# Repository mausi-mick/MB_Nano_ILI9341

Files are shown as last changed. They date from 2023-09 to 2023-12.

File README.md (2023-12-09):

.
    Test Board für Arduino „NANOs“ mit ILI9341, ILI9488-bzw. ST7735 SPI-Display

Bei vielen meiner Projekte  verwende ich den Arduino NANO oder Pin-kompatible Prozessoren mit dem TFT-Farb-Display ILI9341 bzw. ILI9488 bzw. ST7735 aus folgenden Gründen:
  
    • Existenz vieler Bibliotheken (libs) mit zahlreichen Beispielen für Prozessor und Display
    • kompaktes Board mit relativ grosser Anzahl herausgeführter Pins für andere Funktionen,
    • leicht beschaffbar / preisgünstig
    • Existenz von „NANO“  Boards mit anderem Processor mit NANO-“Pin-mapping“
    • mit HW-SPI ist das Display -auch am NANO – relativ schnell
    • die SPI-Displays ILI9341, ILI9488 und ST7735 haben gleiche/ähnliche Pinbelegung 
    • unterschiedliche Displaygrössen (1.8“,2,4“,2.8“,3.2“.3.5“,4“) (mit/ohne Touch) erhältlich
    • unterschiedliche Auflösungen (128x160), (240x320), (320x 400)

mittlerweile sind zum Arduino-NANO pinkompatible Boards erhältlich, z.B. :
  
    • LGT8F328P----»Mini EVB Nano style“, Prozessor: modifzierter ATMega328
    • Arduino EVERY:                                     Prozessor: ATMega4809
    • Arduino NANO ESP32                           ,Prozessor: ESP32
    • Arduino NANO 33 BLE                         ,Prozessor: nRF52840
    • Arduino NANO 33 IOT                         , Prozessor: M0+SAMD21
    • Arduino NANO RP2040 Connect          ,Prozessor: RP2040

Die neueren Boards sind dann eher auf 3,3 V Logik ausgerichtet bzw. z.T. umlötbar.

Als Entwickler möchte ich eigentlich möglichst schnell zur Anwendung kommen und mich nicht 
mit den Logik-Leveln rumschlagen , sondern den Prozessor und das Display auf ein
Board setzen und mit der Entwicklung loslegen., möglichst ohne viele Leitugen zu verlegen. 

Daher habe ich dieses Board entwickelt, auf dem Steckfassungen für das Display und das „NANO“-Board angeordnet sind und zusätzlich noch Steck Buchsen für:
    • einen DUAL-DAC MCP48x2
    • bis zu vier Drehencoder ( bzw. Potis),
    • vier Drucktaster
    • vier LED Anzeigen
    • ein Mini-Breadboard 
    • negative Sapnnungsquelle(-5V / ca 100mA) für Oper.verstärker

Das SPI-Display ( ILI9341, ILI9488, ST7735) wird direkt auf das Board gesteckt , auf dem sich die Verdrahtung für die Spannungsversorgung und die SPI-Anschlüsse (CS (Chipselect) an D10, DC (Data/Control) an D9)  des Displays befindet. Die Touch Pins und die SD-Karten Pins des Displays sind auf Buchsenleisten herausgeführt, ebenso wie alle Prozessor-Pins.

Es sind Displays in den Grössen 1.8“(ST7735), 2.4, 2.8 , 3.2“ (ILI9341) bzw. 3.5, 4.0“ (ILI9488) verwendbar.

Alles ist auf einer einlagigen Platine im Europa-Format (160x100) untergebracht.
Die Stromversorgung des Boards und die Programmierung erfolgt vom PC / Notebook über ein USB-Kabel, der Strom ist mit  500 mA abgesichert.
Ist die Programmierung abgeschlossen, kann das Board auch über eine USB Powerbank betrieben werden.

Nur für grössere Verbraucher (Servos, Motoren, Relais,…) wird eine zusätzliche entsprechend
dimensionierte Spannungsversorgung benötigt.

Von diesem „Main“ Board sind die „NANO“ Boards zur Programmierung über kurze USB Kabel verbunden, je nach Board mit Mini-USB (NANO), Micro-USB (Arduino EVERY, LTG8F328) oder
USB-C (LGT8F328 (blaue Platine),.

Zu dem Board gibt es KiCad-files (KiCad 7.0) und ein Blockdiagramm (DrawIO), auch als pdf.

Ausserdem gibt es noch zwei Adapter-Platinen für
den  
            Adafruit-Metro Mini 328
   
und den

            Raspberry PICO RP2040 (W) 
  Ausserdem werden Testprogramme zu den einzelnen Boards und Displays beigefügt.

   Hardware-Komponenten

hier sind jetzt nur die wesentlichen Komponenten / Module aufgeführt, die Details kann man den KiCad Stücklisten entnehmen.

    • ILI9341 SPI-Display (2.4“, 2.8“ oder 3.2“) (Touch bzw ohne Touch) (240x320 Pixel)
    • bzw ILI9488 Display (3,5“ bzw. 4.0“)  (Touch bzw ohne Touch) (320x400 Pixel)
    • bzw. ST7735 Display( 1.8“)  ohne Touch (128x160 Pixel)
    • Arduino NANO  oder Varianten gleicher Pin-Belegung 
    • USB C Buchse zur Verbindung PC/Notebbok
    • USB-A-Buchsezur Verbindung zum Prozesorboard
    • je nach Prozessorboard kurzes USB-Kabel mit mini-, micro USB-Stecker / USB-C-Stecker
    • diverse Buchsenleisten Raster 2.54 mm
    • LDO variabel ( MC33269) für 3.7V aus 5V
    • Schiebeschalter/Kippscahlter 1x UM)
    • diverse Widerstände, Kondenatoren ,  Dioden und Sicherungen
    • optional:
    •    DualDAC MCPM4802, MCP4812, MCP4822 ( 8, 10,12 bit SPI 
    •    1x DIL8-Fassung
    •    4xButtonSwitch
    •    4xLeds
    •    Dreh-Encoder (0-4 Stück)  ??
    •    Mini-Bread-Board
    •    -negatve Spannungsverorgung mit ICL7662 Modul
    •   Adapterboards für Adafruit Metro-Mini 328 / Raspberry PI RP2040

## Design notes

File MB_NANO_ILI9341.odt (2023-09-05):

MB_NANO_ILI9341

The MB_NANO_ILI9341 is a small „Motherboard“ (160mmx100mm) for developing projects with microprocessor boards with formfactor Arduino NANO (boards: NANO, EVERY, NANO ESP32 , LGT8F328…) and then TFT-Display ILI9341 (3,2“,2,8“, 2.4“).

There are sockets for them and also for other often used devices like rotary encoders / potentiometers , button-switches, LEDs

Powerd via USB connection From PC or Notebook.

You can use it with 5V or 3,3V logic level.

At this time testedt with NANO, NANO EVERY, LGT8f328P and Adafruit METRO Mini 328 (with other PinOut/Pinmapping).

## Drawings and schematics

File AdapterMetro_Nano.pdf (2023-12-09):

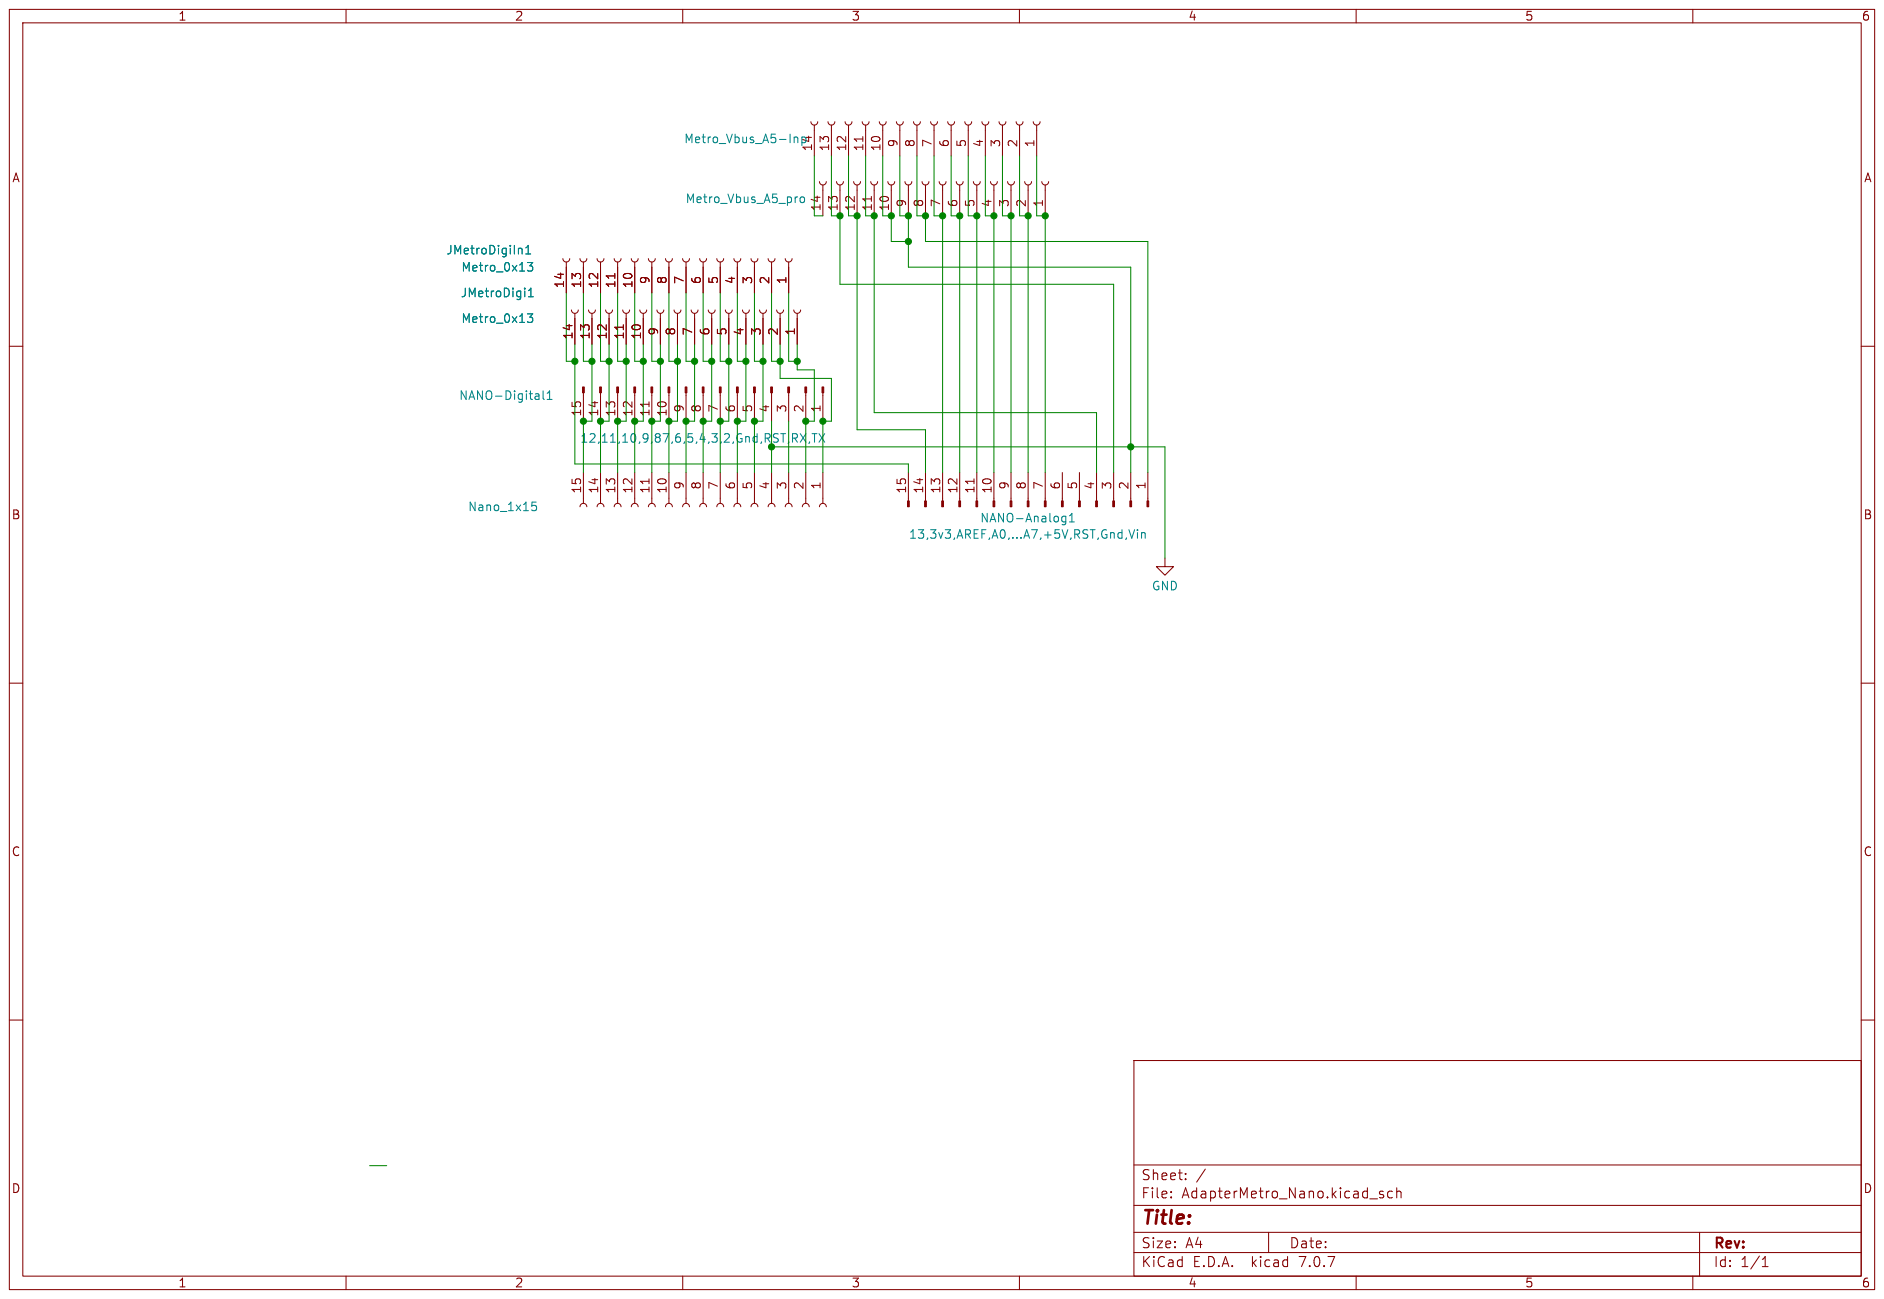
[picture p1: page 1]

12,11,10,9,87,6,5,4,3,2,Gnd,RST,RX,TX

Id: 1/1 Title: File: AdapterMetro_Nano.kicad_sch Sheet: /

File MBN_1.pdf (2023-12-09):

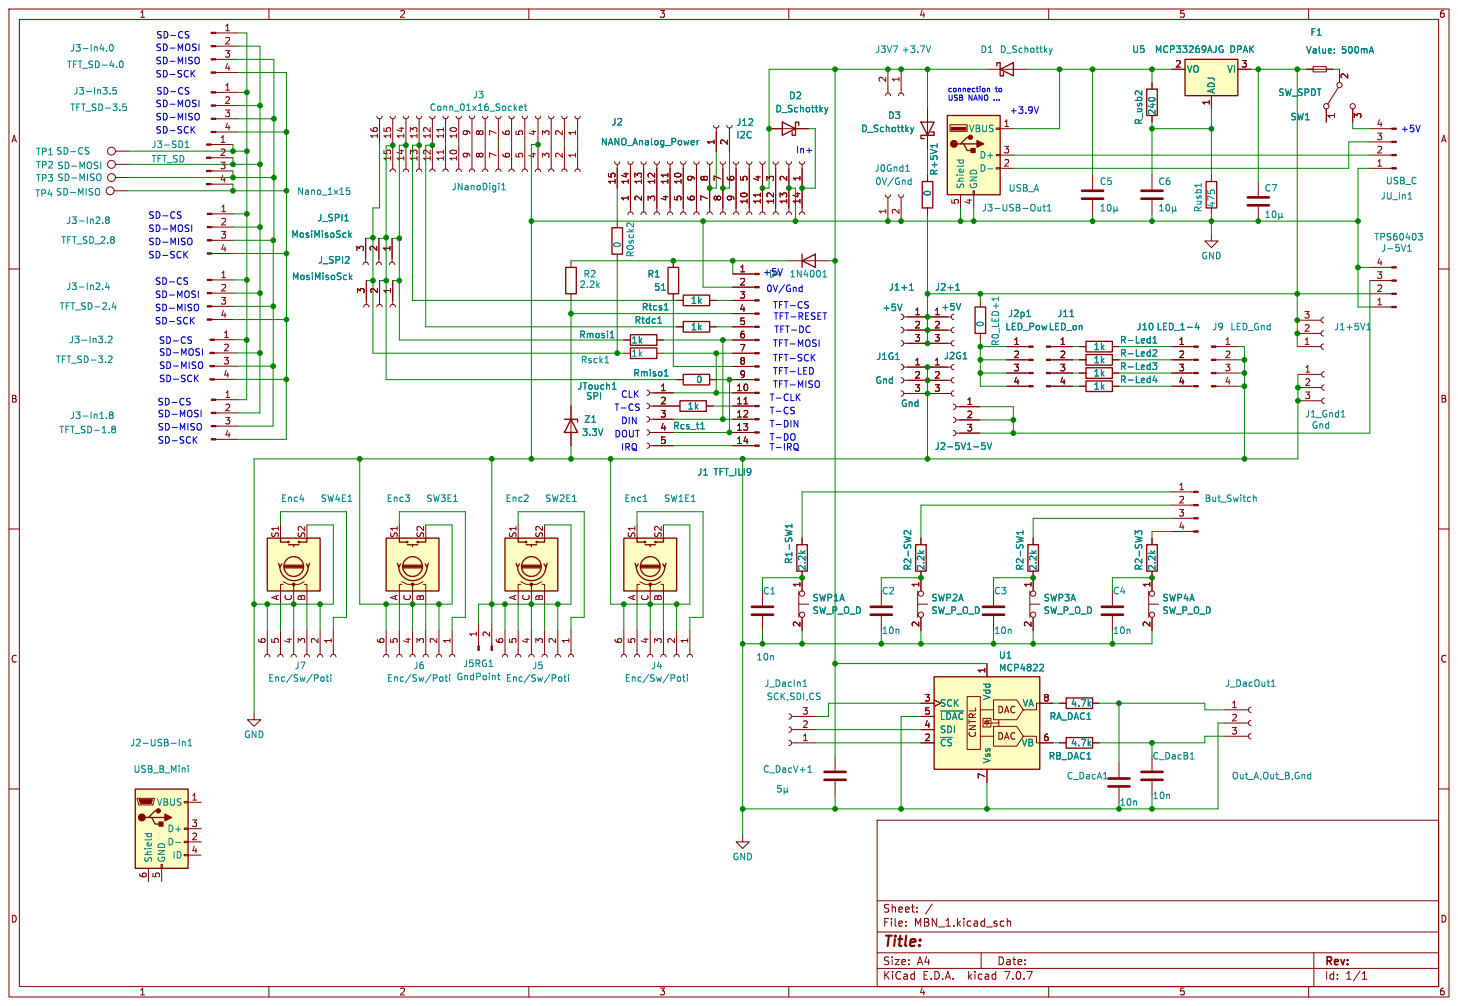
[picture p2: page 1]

SD-MOSI SD-CS
J3-USB-Out1 USB_A D1 D_Schottky SD-SCK

SD-MOSI SD-SCK
SD-MISO

J3-SD1 TFT_SD TP2 SD-MOSI TP3 SD-MISO

1 ~{CS} 2 SCK 3 SDI 4 ~{LDAC} 5 VB 6 Vss 7 VA 8 U1 MCP4822

1 ~{CS} 2 SCK 3 SDI 4 ~{LDAC} 5 VB 6 Vss 7 VA 8RB_DAC1

Id: 1/1 Title: File: MBN_1.kicad_sch Sheet: /

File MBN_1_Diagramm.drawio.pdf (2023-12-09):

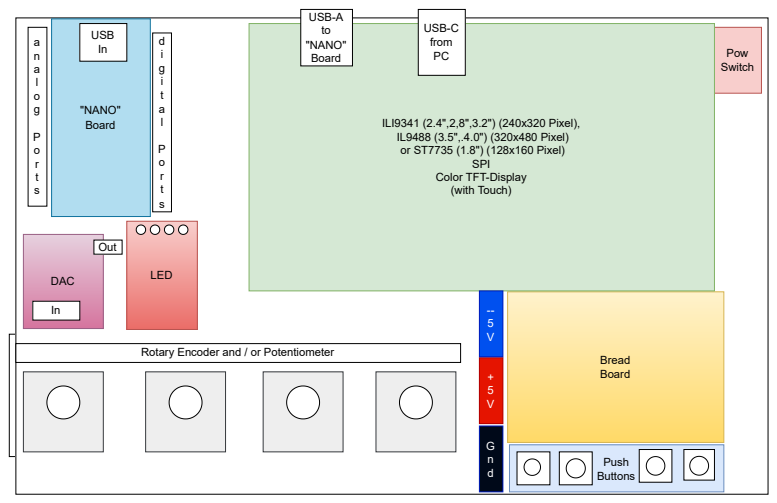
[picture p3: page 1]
"NANO" Board; DAC; Bread Board; Push Buttons; Pow Switch; LED; USB In; Out; ILI9341 (2.4",2,8",3.2") (240x320 Pixel), IL9488 (3.5",.4.0") (320x480 Pixel) or ST7735 (1.8") (128x160 Pixel); USB-A to "NANO" Board; USB-C from PC

SPI
Color TFT-Display
(with Touch)

Rotary Encoder and / or Potentiometer

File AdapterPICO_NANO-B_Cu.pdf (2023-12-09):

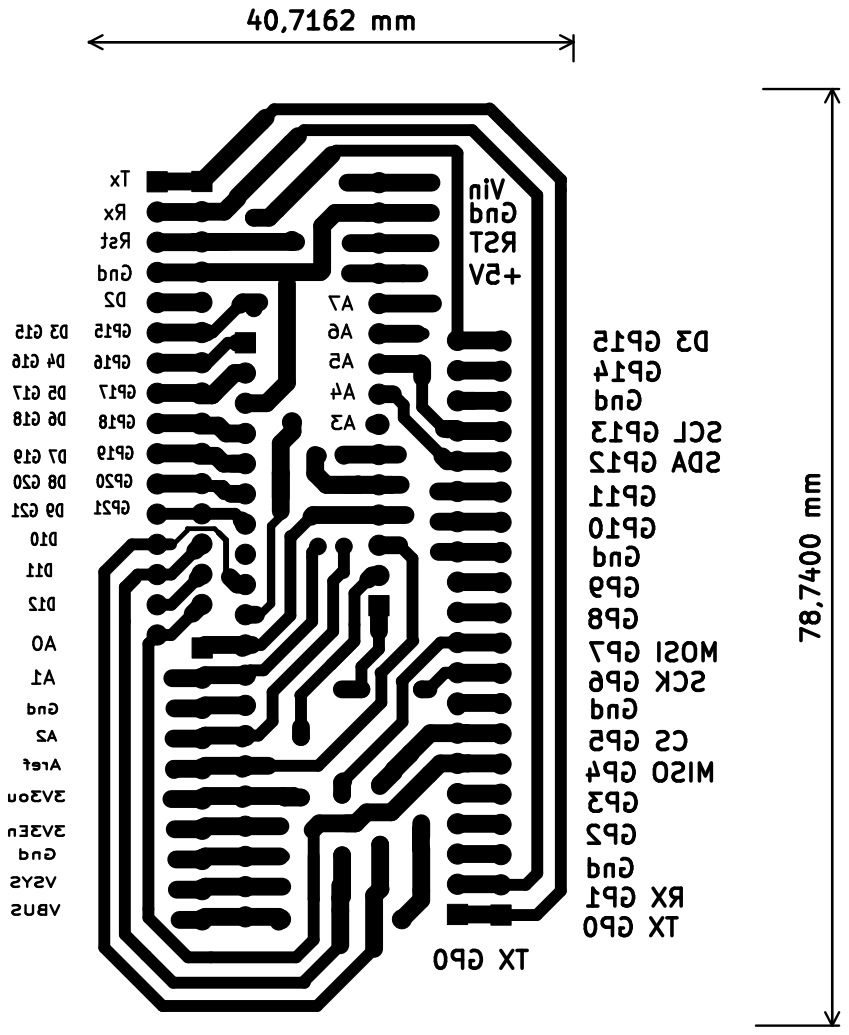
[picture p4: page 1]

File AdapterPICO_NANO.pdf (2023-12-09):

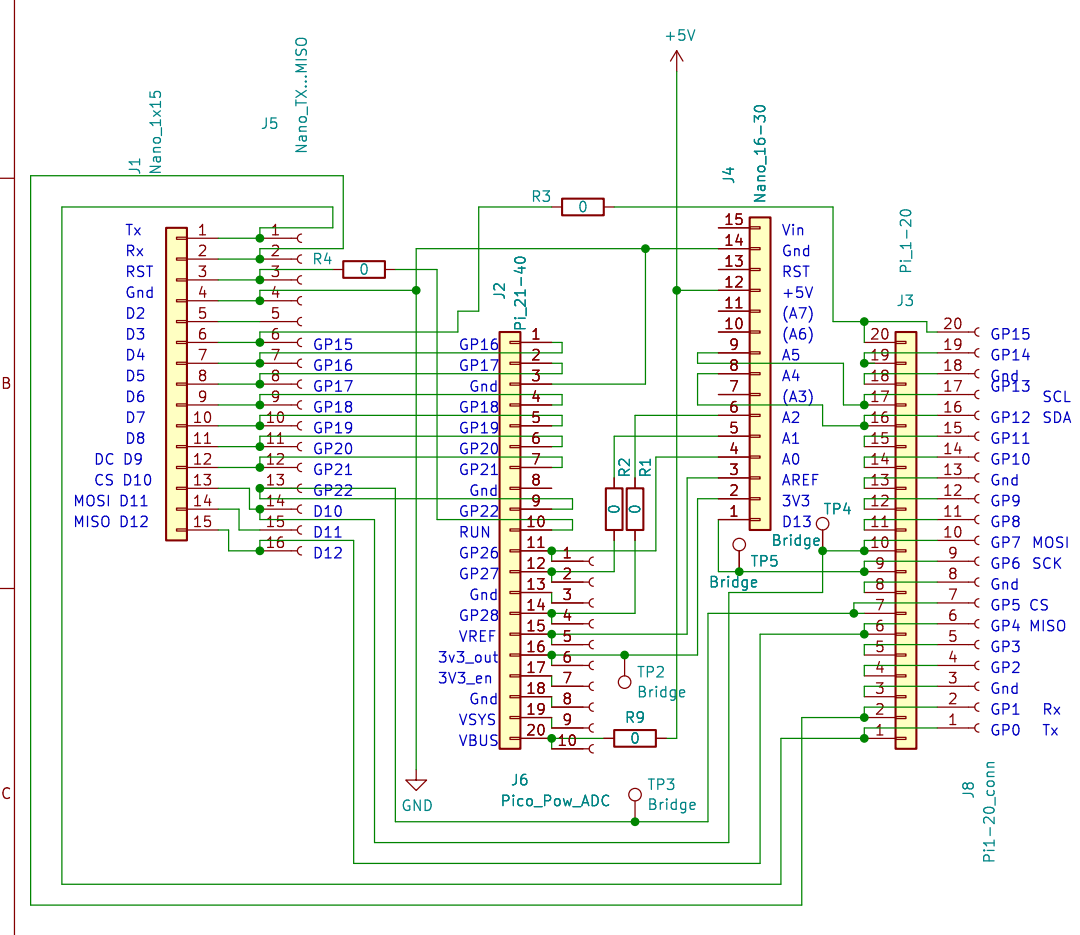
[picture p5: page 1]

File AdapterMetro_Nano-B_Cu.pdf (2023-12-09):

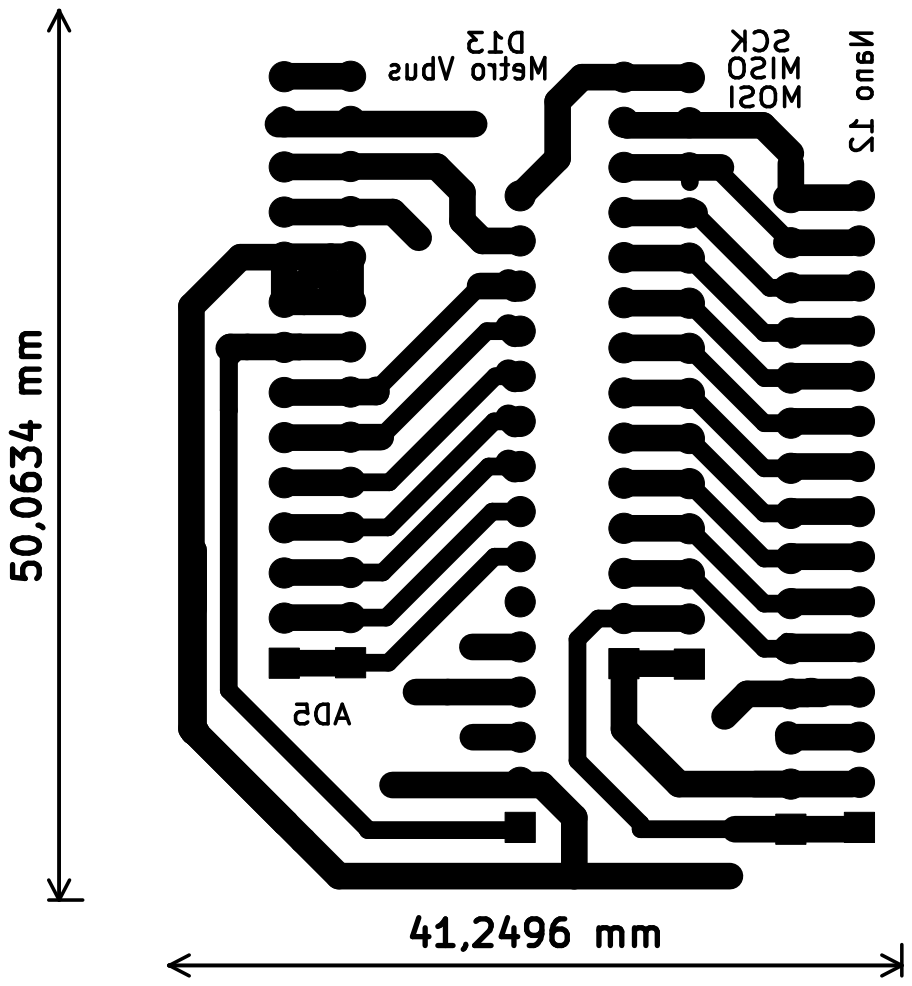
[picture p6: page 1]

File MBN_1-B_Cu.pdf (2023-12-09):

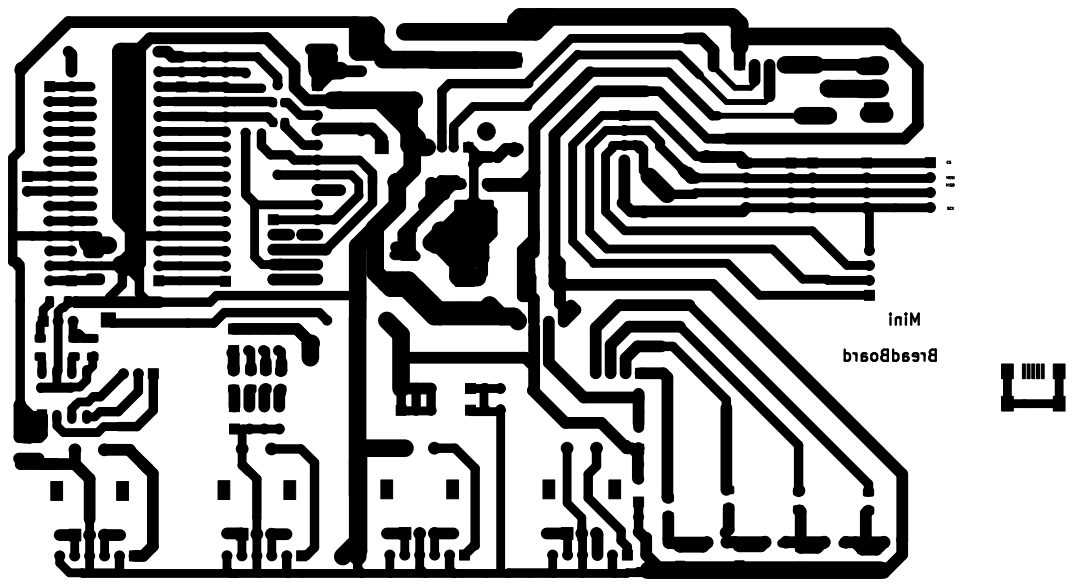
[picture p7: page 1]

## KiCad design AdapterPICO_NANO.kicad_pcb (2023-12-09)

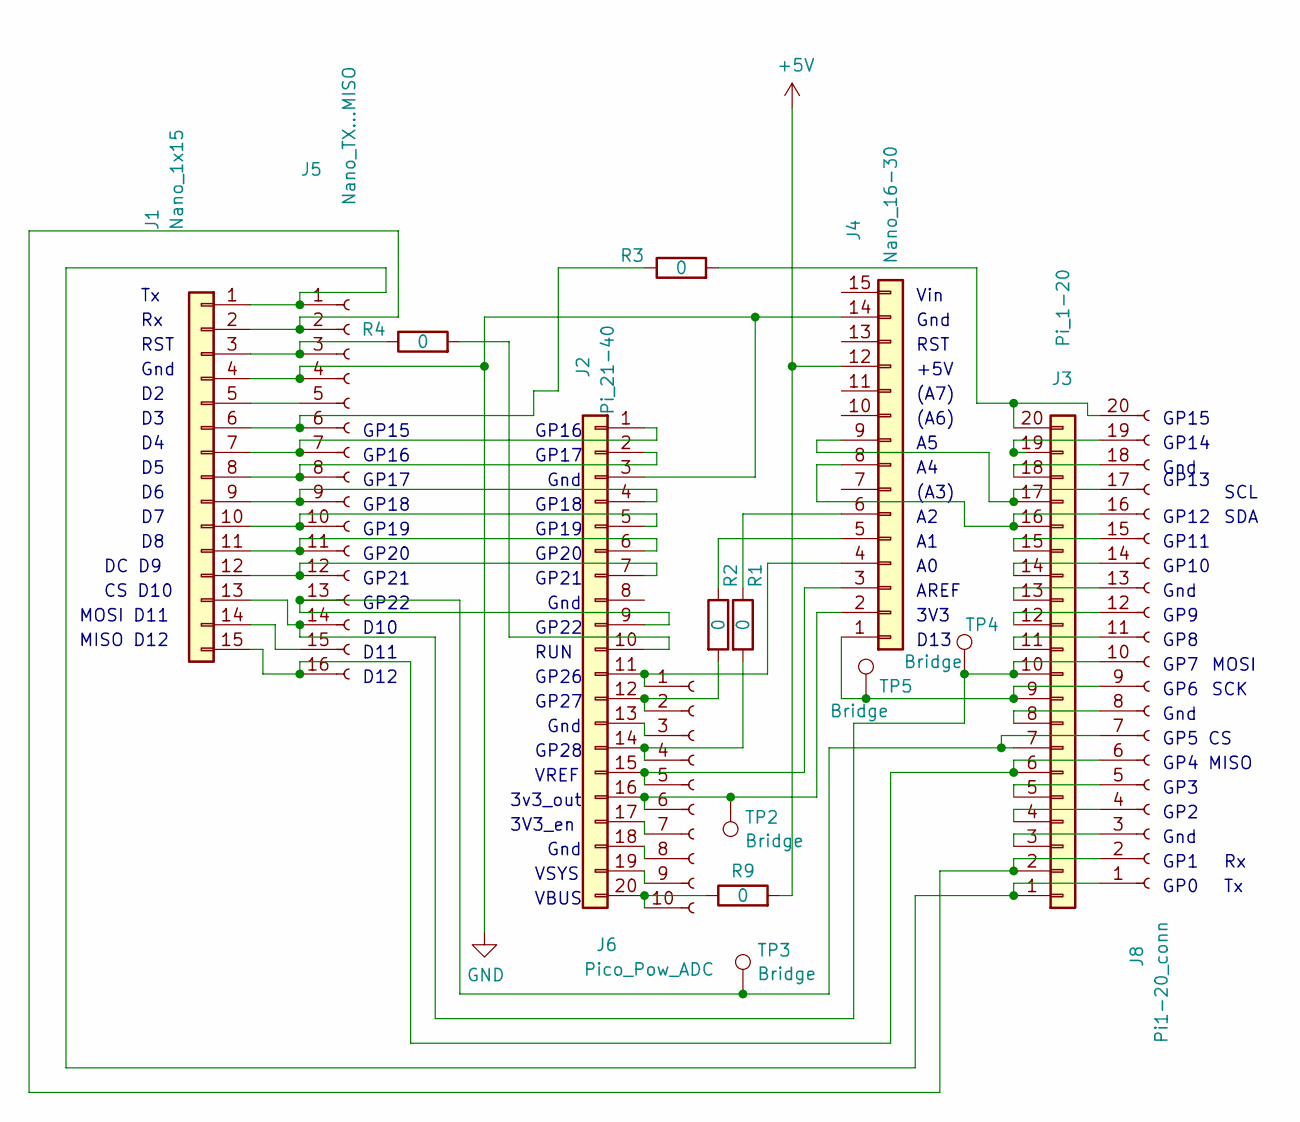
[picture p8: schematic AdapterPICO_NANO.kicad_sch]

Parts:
J1: Nano_1x15; PinHeader_1x15_P2.54mm_Vertical
J2: Pi_21-40; PinSocket_1x20_P2.54mm_Vertical
J3: Pi_1-20; PinSocket_1x20_P2.54mm_Vertical
J4: Nano_16-30; PinHeader_1x15_P2.54mm_Vertical
J5: Nano_TX...MISO; PinSocket_1x16_P2.54mm_Vertical
J6: Pico_Pow_ADC; PinSocket_1x10_P2.54mm_Vertical
J8: Pi1-20_conn; PinSocket_1x20_P2.54mm_Vertical
R1, R2, R3: 0; R_Axial_DIN0204_L3.6mm_D1.6mm_P7.62mm_Horizontal
R4: 0; R_Axial_DIN0207_L6.3mm_D2.5mm_P15.24mm_Horizontal
R9: 0; R_Axial_DIN0207_L6.3mm_D2.5mm_P10.16mm_Horizontal
TP2, TP3, TP4, TP5: Bridge; TestPoint_Bridge_Pitch5.08mm_Drill0.7mm

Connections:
+5V: J4.12, R9.2
GND: J1.4, J2.3, J4.14, J5.4
unnamed: J1.1, J3.1, J5.1, J8.1
unnamed: J1.2, J3.2, J5.2, J8.2
unnamed: J1.3, J5.3, R4.1
unnamed: J1.5, J5.5
unnamed: J1.6, J5.6, R3.1
unnamed: J1.7, J2.1, J5.7
unnamed: J1.8, J2.2, J5.8
unnamed: J1.9, J2.4, J5.9
unnamed: J1.10, J2.5, J5.10
unnamed: J1.11, J2.6, J5.11
unnamed: J1.12, J2.7, J5.12
unnamed: J1.13, J3.10, J5.14, J8.10, TP4.1
unnamed: J1.14, J5.15
unnamed: J1.15, J3.6, J5.16, J8.6
unnamed: J2.9, J3.7, J5.13, J8.7, TP3.1
unnamed: J2.10, R4.2
unnamed: J2.11, J4.4, J6.1
unnamed: J2.12, J6.2, R2.2
unnamed: J2.13, J6.3
unnamed: J2.14, J6.4, R1.2
unnamed: J2.15, J4.3, J6.5
unnamed: J2.16, J4.2, J6.6, TP2.1
unnamed: J2.17, J6.7
unnamed: J2.18, J6.8
unnamed: J2.19, J6.9
unnamed: J2.20, J6.10, R9.1
unnamed: J3.3, J8.3
unnamed: J3.4, J8.4
unnamed: J3.5, J8.5
unnamed: J3.8, J8.8
unnamed: J3.9, J4.1, J8.9, TP5.1
unnamed: J3.11, J8.11
unnamed: J3.12, J8.12
unnamed: J3.13, J8.13
unnamed: J3.14, J8.14
unnamed: J3.15, J8.15
unnamed: J3.16, J4.8, J8.16
unnamed: J3.17, J4.9, J8.17
unnamed: J3.18, J8.18
unnamed: J3.19, J8.19
unnamed: J3.20, J8.20, R3.2
unnamed: J4.5, R2.1
unnamed: J4.6, R1.1

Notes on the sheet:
D10
Vin
GP26
SDA
GP16
GP12
GP13
RST
GP9
VBUS
GP5 CS
CS D10
SCL
MOSI
GP20
GP7
3V3
DC D9
Gnd
GP15
GP3
(A6)
MISO D12
GP19
GP27
GP18
VSYS
D11
GP21
GP14
D12
SCK
(A3)
GP11
AREF
GP17
GP28
GP0
MOSI D11
RUN

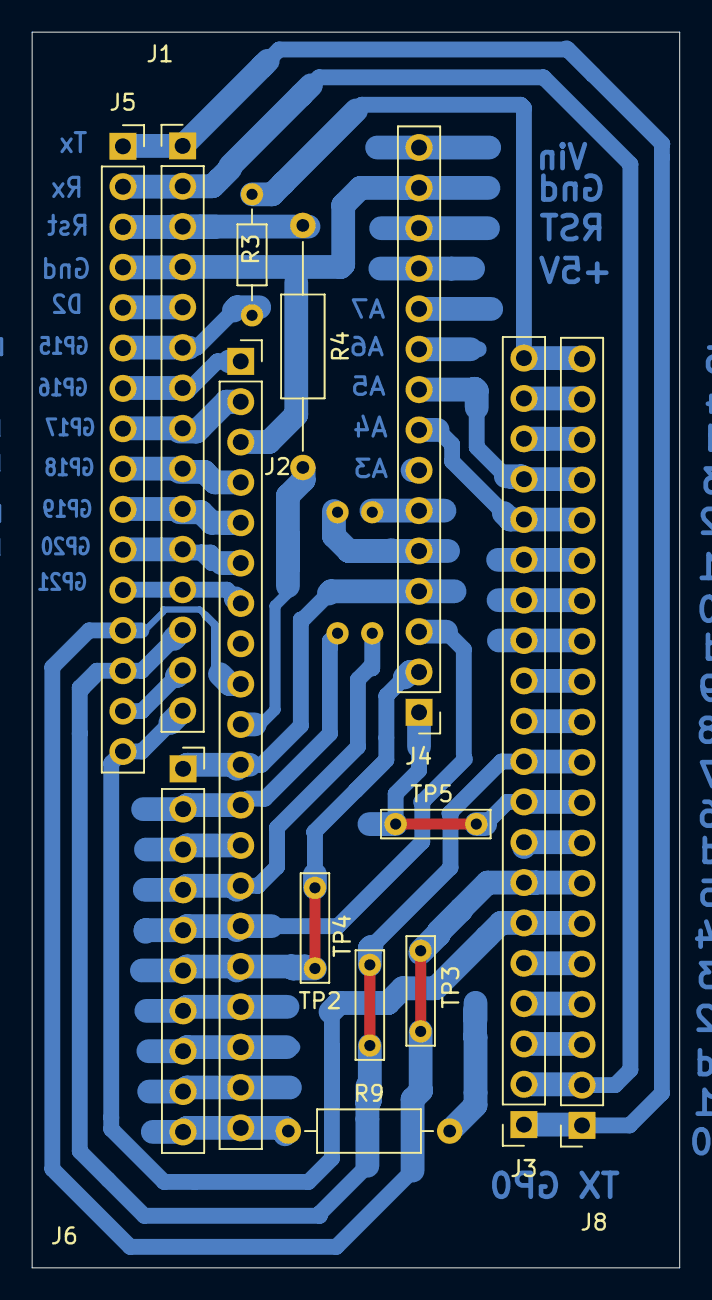
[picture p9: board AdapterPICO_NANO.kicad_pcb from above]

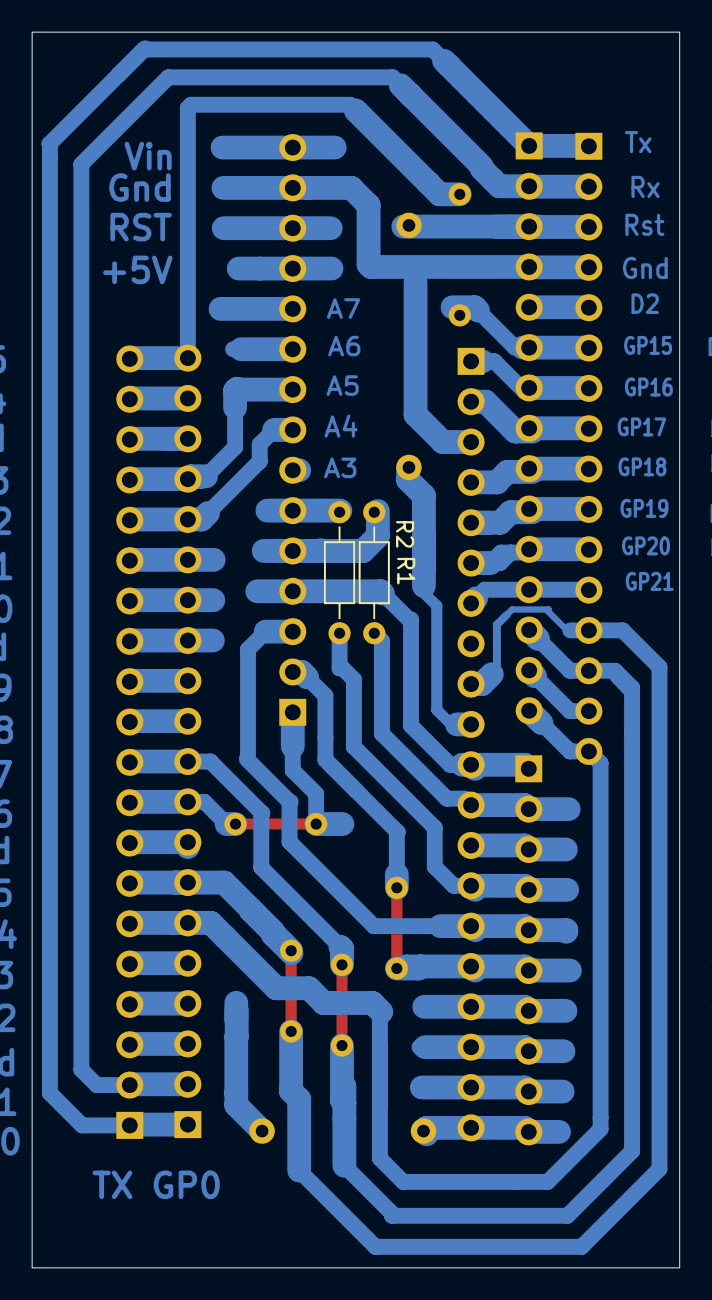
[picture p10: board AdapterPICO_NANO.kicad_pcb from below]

Board: 2 copper layers, 40.8 x 77.8 mm, 16 parts (2 on the bottom side), 45 nets.

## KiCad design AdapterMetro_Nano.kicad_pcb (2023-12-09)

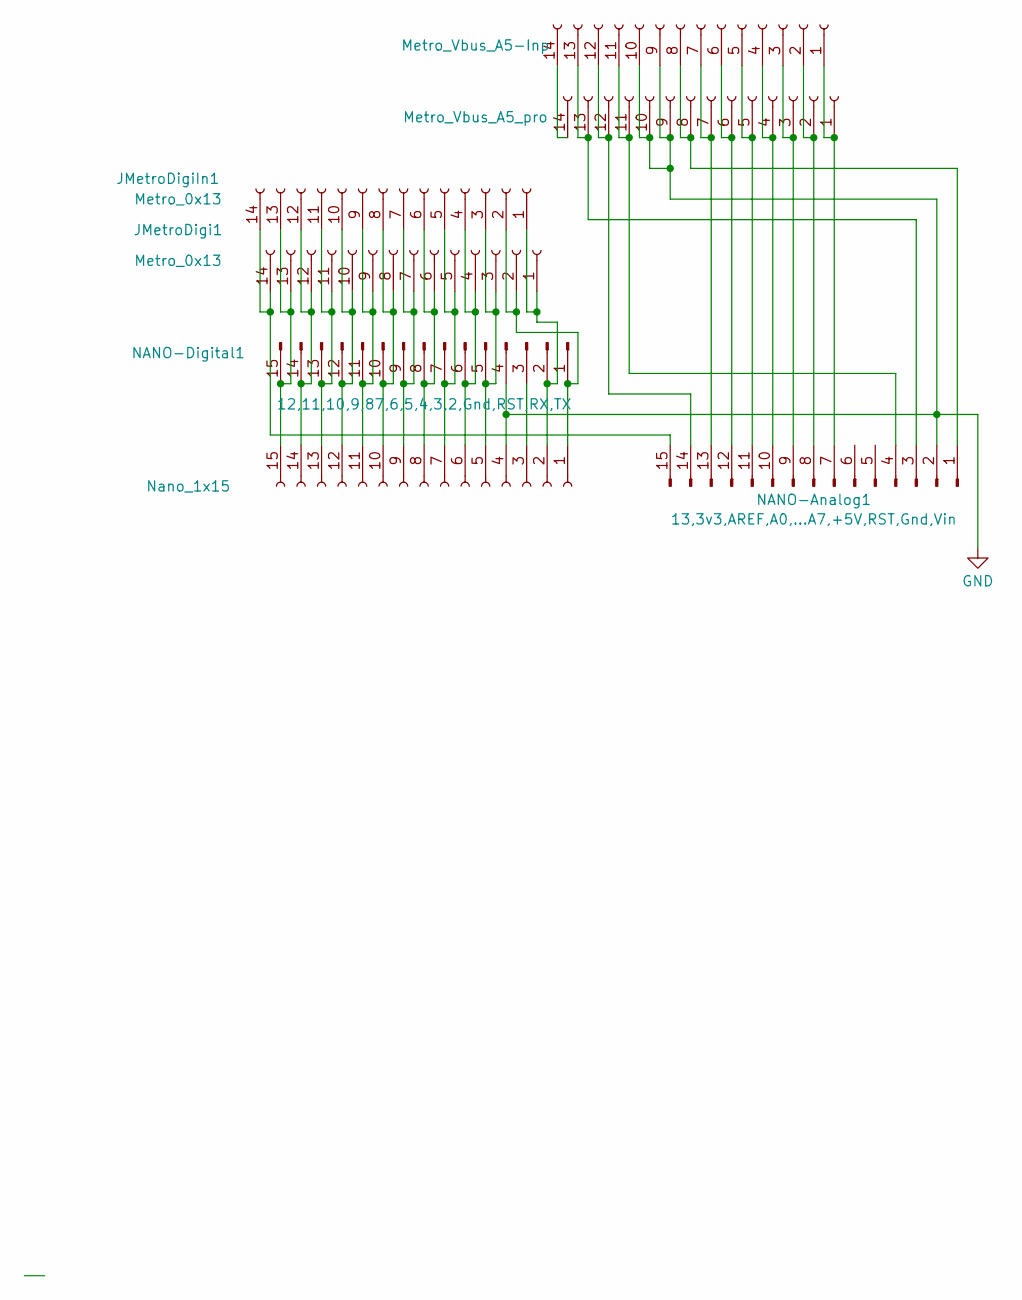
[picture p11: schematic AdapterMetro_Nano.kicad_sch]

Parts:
JMetroAna1: Metro_Vbus_A5-Inp; PinSocket_1x14_P2.54mm_Vertical
JMetroAna2: Metro_Vbus_A5_pro; PinSocket_1x14_P2.54mm_Vertical
JMetroDigi1: Metro_0x13; PinSocket_1x14_P2.54mm_Vertical
JMetroDigiIn1: Metro_0x13; PinSocket_1x14_P2.54mm_Vertical
JNanoDigi2: Nano_1x15; PinSocket_1x15_P2.54mm_Vertical
NANO-Analog1: 13,3v3,AREF,A0,...A7,+5V,RST,Gnd,Vin; PinHeader_1x15_P2.54mm_Vertical
NANO-Digital1: 12,11,10,9,87,6,5,4,3,2,Gnd,RST,RX,TX; PinHeader_1x15_P2.54mm_Vertical

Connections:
GND: JMetroAna1.9, JMetroAna1.10, JMetroAna2.9, JMetroAna2.10, JNanoDigi2.4, NANO-Analog1.2, NANO-Digital1.4
unnamed: JMetroAna1.1, JMetroAna2.1, NANO-Analog1.7
unnamed: JMetroAna1.2, JMetroAna2.2, NANO-Analog1.8
unnamed: JMetroAna1.3, JMetroAna2.3, NANO-Analog1.9
unnamed: JMetroAna1.4, JMetroAna2.4, NANO-Analog1.10
unnamed: JMetroAna1.5, JMetroAna2.5, NANO-Analog1.11
unnamed: JMetroAna1.6, JMetroAna2.6, NANO-Analog1.12
unnamed: JMetroAna1.7, JMetroAna2.7, NANO-Analog1.13
unnamed: JMetroAna1.8, JMetroAna2.8, NANO-Analog1.1
unnamed: JMetroAna1.11, JMetroAna2.11, NANO-Analog1.4
unnamed: JMetroAna1.12, JMetroAna2.12, NANO-Analog1.14
unnamed: JMetroAna1.13, JMetroAna2.13, NANO-Analog1.3
unnamed: JMetroAna1.14, JMetroAna2.14
unnamed: JMetroDigi1.1, JMetroDigiIn1.1, JNanoDigi2.2, NANO-Digital1.2
unnamed: JMetroDigi1.2, JMetroDigiIn1.2, JNanoDigi2.1, NANO-Digital1.1
unnamed: JMetroDigi1.3, JMetroDigiIn1.3, JNanoDigi2.5, NANO-Digital1.5
unnamed: JMetroDigi1.4, JMetroDigiIn1.4, JNanoDigi2.6, NANO-Digital1.6
unnamed: JMetroDigi1.5, JMetroDigiIn1.5, JNanoDigi2.7, NANO-Digital1.7
unnamed: JMetroDigi1.6, JMetroDigiIn1.6, JNanoDigi2.8, NANO-Digital1.8
unnamed: JMetroDigi1.7, JMetroDigiIn1.7, JNanoDigi2.9, NANO-Digital1.9
unnamed: JMetroDigi1.8, JMetroDigiIn1.8, JNanoDigi2.10, NANO-Digital1.10
unnamed: JMetroDigi1.9, JMetroDigiIn1.9, JNanoDigi2.11, NANO-Digital1.11
unnamed: JMetroDigi1.10, JMetroDigiIn1.10, JNanoDigi2.12, NANO-Digital1.12
unnamed: JMetroDigi1.11, JMetroDigiIn1.11, JNanoDigi2.13, NANO-Digital1.13
unnamed: JMetroDigi1.12, JMetroDigiIn1.12, JNanoDigi2.14, NANO-Digital1.14
unnamed: JMetroDigi1.13, JMetroDigiIn1.13, JNanoDigi2.15, NANO-Digital1.15
unnamed: JMetroDigi1.14, JMetroDigiIn1.14, NANO-Analog1.15
unnamed: JNanoDigi2.3, NANO-Digital1.3

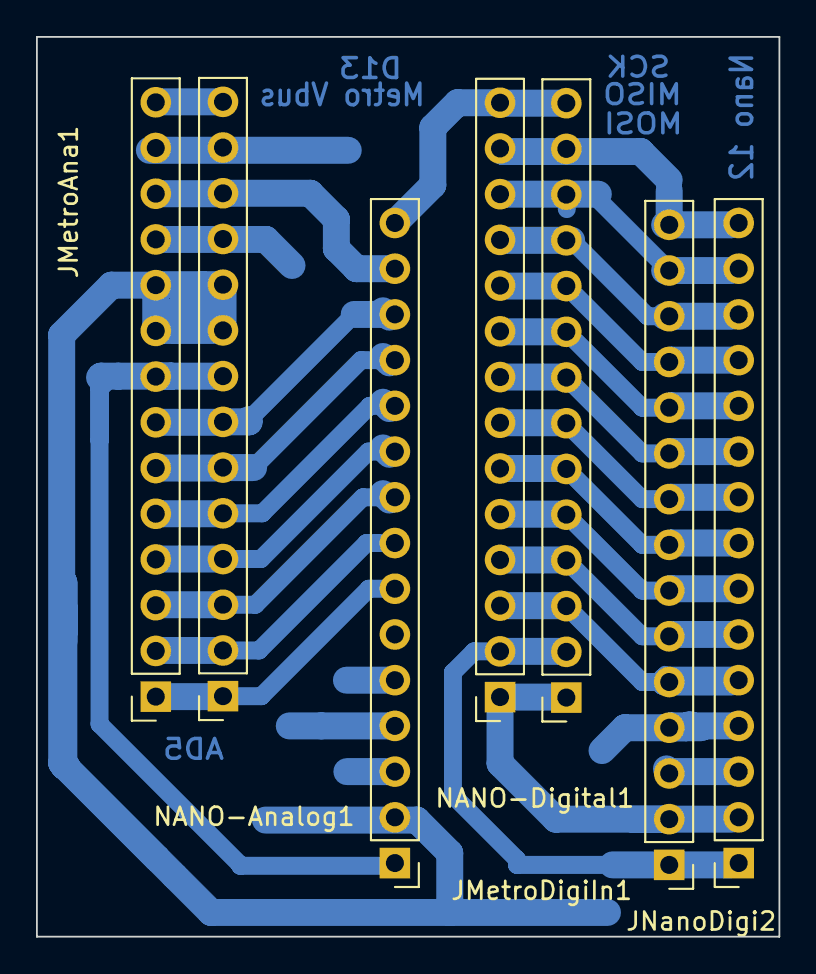
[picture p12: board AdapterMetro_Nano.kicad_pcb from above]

Board: 2 copper layers, 41.2 x 50.0 mm, 7 parts (0 on the bottom side), 28 nets.

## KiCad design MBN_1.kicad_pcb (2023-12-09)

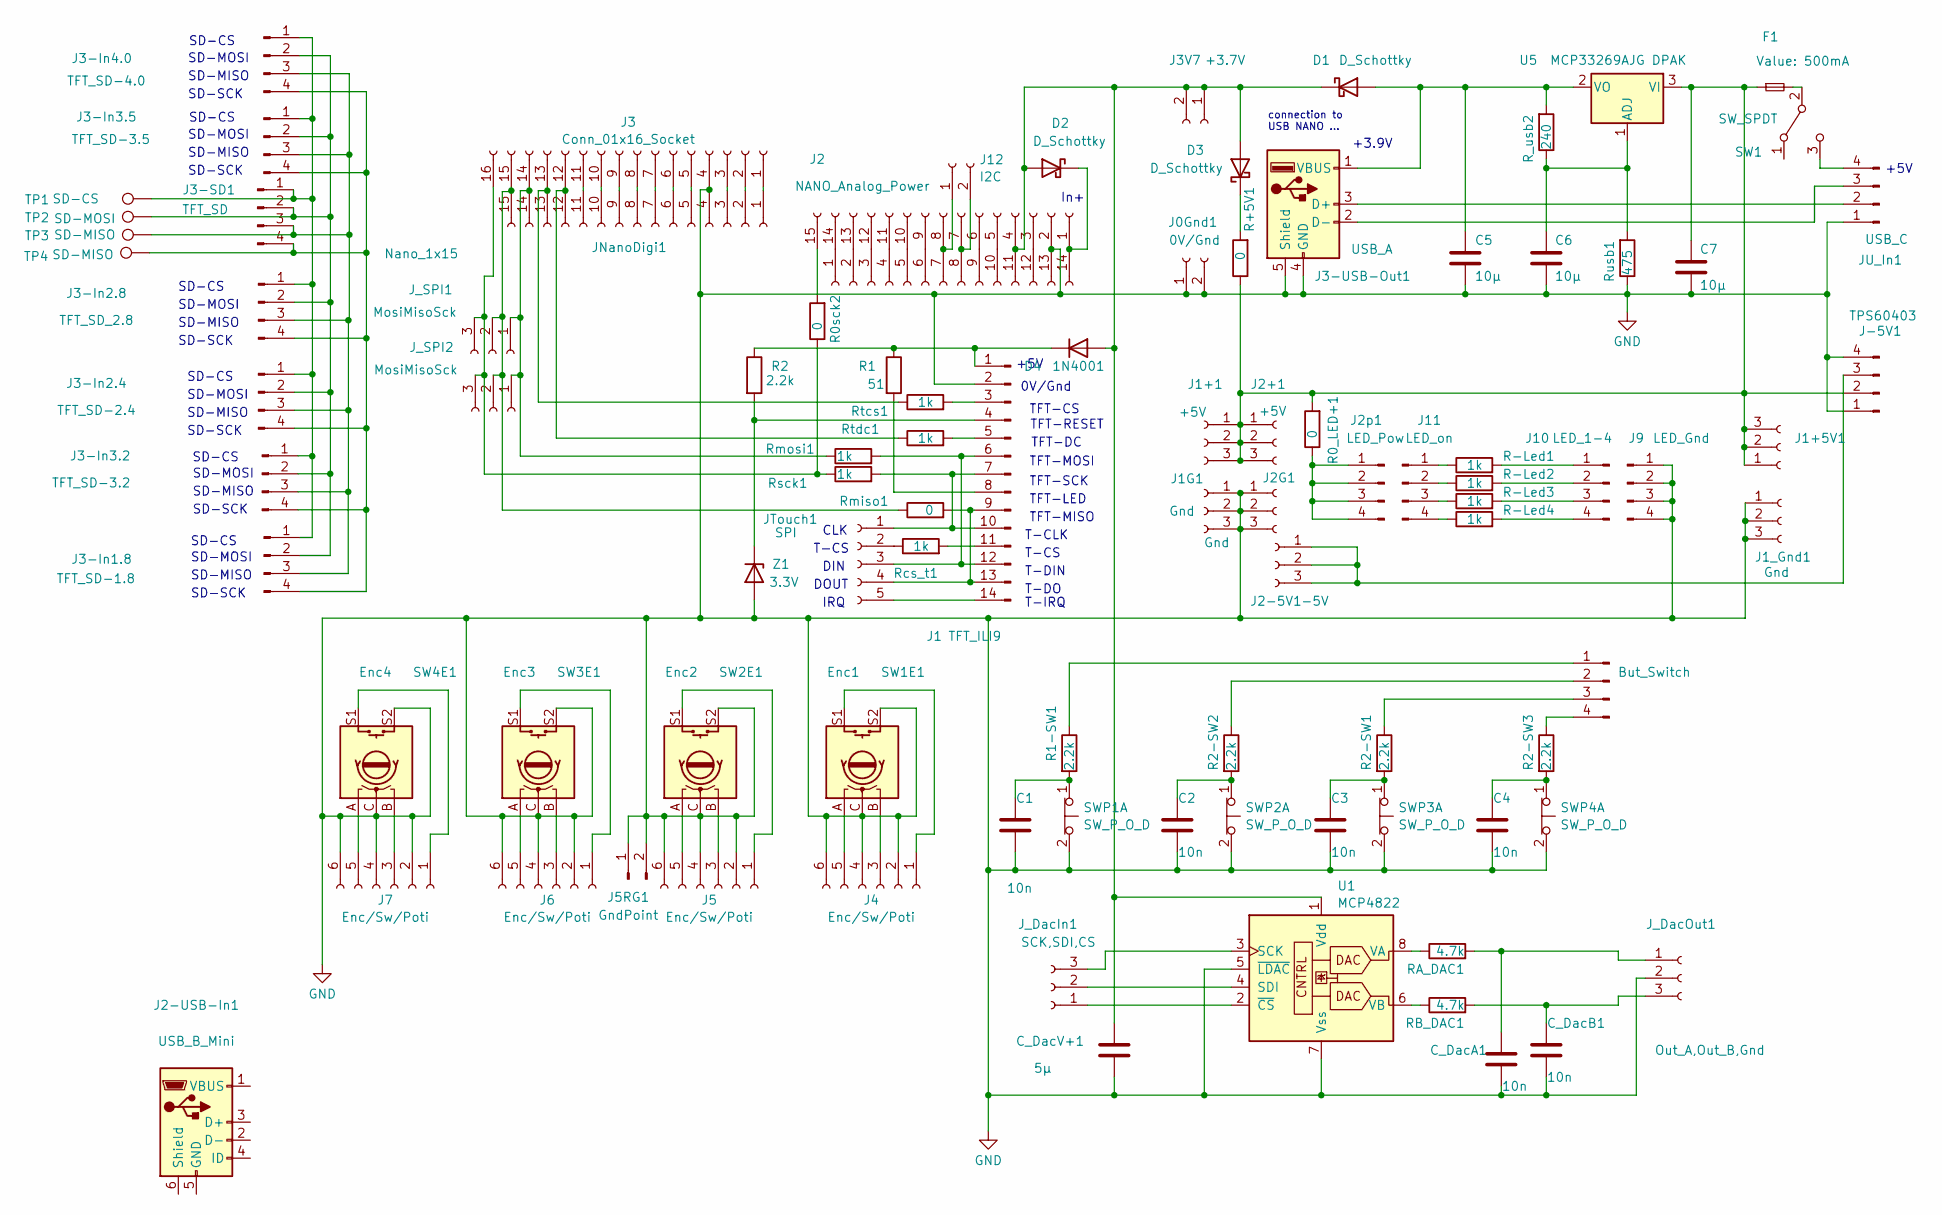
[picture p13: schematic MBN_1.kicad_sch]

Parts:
C1, C2, C3, C4: 10n; C_1206_3216Metric_Pad1.33x1.80mm_HandSolder
C5, C6, C7: 10µ; C_1812_4532Metric_Pad1.57x3.40mm_HandSolder
C_DacA1: 10n; C_1206_3216Metric_Pad1.33x1.80mm_HandSolder
C_DacB1: 10n; C_1206_3216Metric_Pad1.33x1.80mm_HandSolder
C_DacV+1: 5µ; C_1812_4532Metric_Pad1.57x3.40mm_HandSolder
D1: D_Schottky; D_DO-15_P15.24mm_Horizontal
D2: D_Schottky; D_2010_5025Metric_Pad1.52x2.65mm_HandSolder
D3: D_Schottky; D_DO-15_P12.70mm_Horizontal
D4: 1N4001; D_2010_5025Metric_Pad1.52x2.65mm_HandSolder
F1: 500mA; Fuse_2010_5025Metric_Pad1.52x2.65mm_HandSolder
J0Gnd1: 0V/Gnd; PinHeader_1x02_P2.54mm_Vertical
J1: TFT_ILI9; PinHeader_1x14_P2.54mm_Vertical
J1+1, J1+5V1, J2+1: +5V; PinHeader_1x03_P2.54mm_Vertical
J1G1, J1_Gnd1, J2G1: Gnd; PinHeader_1x03_P2.54mm_Vertical
J2: NANO_Analog_Power; PinHeader_1x14_P2.54mm_Vertical
J2-5V1: -5V; PinHeader_1x03_P2.54mm_Vertical
J2-USB-In1: USB_B_Mini; USB_Mini-B_Wuerth_65100516121_Horizontal
J2p1: LED_Pow; PinHeader_1x04_P2.54mm_Vertical
J3: Conn_01x16_Socket; PinHeader_1x16_P2.54mm_Vertical
J3-In1.8: TFT_SD-1.8; PinHeader_1x04_P2.54mm_Vertical
J3-In2.4: TFT_SD-2.4; PinHeader_1x04_P2.54mm_Vertical
J3-In2.8: TFT_SD_2.8; PinSocket_1x04_P2.54mm_Vertical
J3-In3.2: TFT_SD-3.2; PinHeader_1x04_P2.54mm_Vertical
J3-In3.5: TFT_SD-3.5; PinHeader_1x04_P2.54mm_Vertical
J3-In4.0: TFT_SD-4.0; PinHeader_1x04_P2.54mm_Vertical
J3-SD1: TFT_SD; PinHeader_1x04_P2.54mm_Horizontal
J3-USB-Out1: USB_A; USB_A_Stewart_SS-52100-001_Horizontal
J3V7: +3.7V; PinHeader_1x02_P2.54mm_Vertical
J4, J5, J6, J7: Enc/Sw/Poti; PinHeader_1x06_P2.54mm_Vertical
J5RG1: GndPoint; PinHeader_1x02_P2.54mm_Vertical
J8: But_Switch; PinHeader_1x04_P2.54mm_Vertical
J9: LED_Gnd; PinHeader_1x04_P2.54mm_Vertical
J10: LED_1-4; PinHeader_1x04_P2.54mm_Vertical
J11: LED_on; PinHeader_1x04_P2.54mm_Vertical
J12: I2C; PinHeader_1x02_P2.54mm_Vertical
J-5V1: TPS60403; PinHeader_1x04_P2.54mm_Vertical
JNanoAnal_1_15: +InGnd...; PinSocket_1x15_P2.54mm_Vertical
JNanoDigi1: Nano_1x15; PinSocket_1x15_P2.54mm_Vertical
JTouch1: SPI; PinHeader_1x05_P2.54mm_Vertical
JU_In1: USB_C; PinHeader_1x04_P2.54mm_Vertical
J_DacIn1: SCK,SDI,CS; PinHeader_1x03_P2.54mm_Vertical
J_DacOut1: Out_A,Out_B,Gnd; PinHeader_1x03_P2.54mm_Vertical
J_SPI1, J_SPI2: MosiMisoSck; PinHeader_1x03_P2.54mm_Vertical
R0_LED+1, R0sck2: 0; R_Axial_DIN0207_L6.3mm_D2.5mm_P15.24mm_Horizontal
R1: 51; R_Axial_DIN0309_L9.0mm_D3.2mm_P20.32mm_Horizontal
R1-SW1, R2-SW1, R2-SW2, R2-SW3: 2.2k; R_1206_3216Metric_Pad1.30x1.75mm_HandSolder
R2: 2.2k; R_Axial_DIN0207_L6.3mm_D2.5mm_P10.16mm_Horizontal
R+5V1: 0; R_Axial_DIN0207_L6.3mm_D2.5mm_P10.16mm_Horizontal
R-Led1, R-Led2, R-Led3, R-Led4: 1k; R_1206_3216Metric_Pad1.30x1.75mm_HandSolder
RA_DAC1: 4.7k; R_1206_3216Metric_Pad1.30x1.75mm_HandSolder
RB_DAC1: 4.7k; R_1206_3216Metric_Pad1.30x1.75mm_HandSolder
R_usb2: 240; R_Axial_DIN0207_L6.3mm_D2.5mm_P10.16mm_Horizontal
Rcs_t1: 1k; R_0805_2012Metric_Pad1.20x1.40mm_HandSolder
Rmiso1: 0; R_Axial_DIN0207_L6.3mm_D2.5mm_P10.16mm_Horizontal
Rmosi1: 1k; R_Axial_DIN0204_L3.6mm_D1.6mm_P7.62mm_Horizontal
Rsck1: 1k; R_Axial_DIN0207_L6.3mm_D2.5mm_P15.24mm_Horizontal
Rtcs1: 1k; R_0805_2012Metric_Pad1.20x1.40mm_HandSolder
Rtdc1: 1k; R_0805_2012Metric_Pad1.20x1.40mm_HandSolder
Rusb1: 475; R_Axial_DIN0207_L6.3mm_D2.5mm_P10.16mm_Horizontal
SW1: SW_SPDT; Molex_KK-396_5273-03A_1x03_P3.96mm_Vertical
SW1E1: Enc1; RotaryEncoder_Alps_EC11E-Switch_Vertical_H20mm
SW2E1: Enc2; RotaryEncoder_Alps_EC11E-Switch_Vertical_H20mm
SW3E1: Enc3; RotaryEncoder_Alps_EC11E-Switch_Vertical_H20mm
SW4E1: Enc4; RotaryEncoder_Alps_EC11E-Switch_Vertical_H20mm
SWP1, SWP2, SWP3, SWP4: SW_P_O_D; SW_PUSH_6mm_H7.3mm
TP1: SD-CS; TestPoint_Keystone_5000-5004_Miniature
TP2: SD-MOSI; TestPoint_Keystone_5000-5004_Miniature
TP3, TP4: SD-MISO; TestPoint_Keystone_5000-5004_Miniature
U1: MCP4822; DIP-8_W7.62mm_LongPads
U5: MCP33269AJG DPAK; ATPAK-2
Z1: 3.3V; D_DO-41_SOD81_P7.62mm_Horizontal

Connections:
GND: C1.2, C2.2, C3.2, C4.2, C5.2, C6.2, C7.2, C_DacA1.2, C_DacB1.2, C_DacV+1.2, J0Gnd1.1, J0Gnd1.2, J1.2, J1G1.1, J1G1.2, J1G1.3, J1_Gnd1.1, J1_Gnd1.2, J1_Gnd1.3, J2.13, J2G1.1, J2G1.2, J2G1.3, J3.4, J3-USB-Out1.4 (GND), J3-USB-Out1.5 (Shield), J4.2, J4.4, J4.6, J5.2, J5.4, J5.6, J5RG1.1, J5RG1.2, J6.2, J6.4, J6.6, J7.2, J7.4, J7.6, J9.1, J9.2, J9.3, J9.4, J-5V1.1, J-5V1.4, JNanoAnal_1_15.2, JNanoDigi1.4, JU_In1.1, J_DacOut1.2, Rusb1.1, SW1E1.C, SW1E1.S2, SW2E1.C, SW2E1.S2, SW3E1.C, SW3E1.S2, SW4E1.C, SW4E1.S2, SWP1.2, SWP2.2, SWP3.2, SWP4.2, U1.5 (~LDAC), U1.7 (Vss), Z1.2 (A)
unnamed: C1.1, R1-SW1.2, SWP1.1
unnamed: C2.1, R2-SW2.2, SWP2.1
unnamed: C3.1, R2-SW1.2, SWP3.1
unnamed: C4.1, R2-SW3.2, SWP4.1
unnamed: C5.1, D1.2 (A), J3-USB-Out1.1 (VBUS), R_usb2.2, U5.2 (VO)
unnamed: C_DacV+1.1, D1.1 (K), D2.2 (A), D3.2 (A), D4.2 (A), J2.11, J3V7.1, J3V7.2, JNanoAnal_1_15.4, U1.1 (Vdd)
unnamed: D2.1 (K), J2.14, JNanoAnal_1_15.1
unnamed: D3.1 (K), R+5V1.2
unnamed: D4.1 (K), J1.1, R1.1, R2.1
unnamed: J1.3, Rtcs1.2
unnamed: J1.4, R2.2, Z1.1 (K)
unnamed: J1.5, Rtdc1.2
unnamed: J1.8, R1.2
unnamed: J1.7, J1.10, JTouch1.1, Rsck1.2
unnamed: J1.11, Rcs_t1.2
unnamed: J1.6, J1.12, JTouch1.3, Rmosi1.2
unnamed: J1.9, J1.13, JTouch1.4, Rmiso1.2
unnamed: J1.14, JTouch1.5
unnamed: J2.1, JNanoAnal_1_15.14
unnamed: J2.2, JNanoAnal_1_15.13
unnamed: J2.3, JNanoAnal_1_15.12
unnamed: J2.4, JNanoAnal_1_15.11
unnamed: J2.5, JNanoAnal_1_15.10
unnamed: J2.6, JNanoAnal_1_15.9
unnamed: J2.9, JNanoAnal_1_15.6
unnamed: J2.10, JNanoAnal_1_15.5
unnamed: J2.12, JNanoAnal_1_15.3
unnamed: J2p1.1, J2p1.2, J2p1.3, J2p1.4, R0_LED+1.1
unnamed: J3-In1.8.1, J3-In2.4.1, J3-In2.8.1, J3-In3.2.1, J3-In3.5.1, J3-In4.0.1, J3-SD1.1, TP1.1
unnamed: J3-In1.8.2, J3-In2.4.2, J3-In2.8.2, J3-In3.2.2, J3-In3.5.2, J3-In4.0.2, J3-SD1.2, TP2.1
unnamed: J3-In1.8.3, J3-In2.4.3, J3-In2.8.3, J3-In3.2.3, J3-In3.5.3, J3-In4.0.3, J3-SD1.3, TP3.1
unnamed: J3-In1.8.4, J3-In2.4.4, J3-In2.8.4, J3-In3.2.4, J3-In3.5.4, J3-In4.0.4, J3-SD1.4, TP4.1
unnamed: J3.1, JNanoDigi1.1
unnamed: J3.2, JNanoDigi1.2
unnamed: J3.3, JNanoDigi1.3
unnamed: J3.5, JNanoDigi1.5
unnamed: J3.6, JNanoDigi1.6
unnamed: J3.7, JNanoDigi1.7
unnamed: J3.8, JNanoDigi1.8
unnamed: J3.9, JNanoDigi1.9
unnamed: J3.10, JNanoDigi1.10
unnamed: J3.11, JNanoDigi1.11
unnamed: J3.12, JNanoDigi1.12, Rtdc1.1
unnamed: J3.13, JNanoDigi1.13, Rtcs1.1
unnamed: J3.14, JNanoDigi1.14, J_SPI1.1, J_SPI2.1, Rmosi1.1
unnamed: J3.15, JNanoDigi1.15, J_SPI1.2, J_SPI2.2, Rmiso1.1
unnamed: J3.16, J_SPI1.3, J_SPI2.3, R0sck2.1, Rsck1.1
unnamed: J3-USB-Out1.3 (D+), JU_In1.2
unnamed: J3-USB-Out1.2 (D-), JU_In1.3
unnamed: J4.1, SW1E1.S1
unnamed: J4.3, SW1E1.B
unnamed: J4.5, SW1E1.A
unnamed: J5.1, SW2E1.S1
unnamed: J5.3, SW2E1.B
unnamed: J5.5, SW2E1.A
unnamed: J6.1, SW3E1.S1
unnamed: J6.3, SW3E1.B
unnamed: J6.5, SW3E1.A
unnamed: J7.1, SW4E1.S1
unnamed: J7.3, SW4E1.B
unnamed: J7.5, SW4E1.A
unnamed: J8.1, R1-SW1.1
unnamed: J8.2, R2-SW2.1
unnamed: J8.3, R2-SW1.1
unnamed: J8.4, R2-SW3.1
unnamed: J10.1, R-Led1.2
unnamed: J10.2, R-Led2.2
unnamed: J10.3, R-Led3.2
unnamed: J10.4, R-Led4.2
unnamed: J11.1, R-Led1.1
unnamed: J11.2, R-Led2.1
unnamed: J11.3, R-Led3.1
unnamed: J11.4, R-Led4.1
unnamed: J2.7, J12.1, JNanoAnal_1_15.8
unnamed: J2.8, J12.2, JNanoAnal_1_15.7
unnamed: C7.1, F1.1, J1+1.1, J1+1.2, J1+1.3, J1+5V1.1, J1+5V1.2, J1+5V1.3, J2+1.1, J2+1.2, J2+1.3, J-5V1.2, R0_LED+1.2, R+5V1.1, U5.3 (VI)
unnamed: J2-5V1.1, J2-5V1.2, J2-5V1.3, J-5V1.3
unnamed: JNanoAnal_1_15.15, R0sck2.2
unnamed: JTouch1.2, Rcs_t1.1
unnamed: JU_In1.4, SW1.3 (C)
unnamed: J_DacIn1.1, U1.2 (~CS)
unnamed: J_DacIn1.2, U1.4 (SDI)
unnamed: J_DacIn1.3, U1.3 (SCK)
unnamed: C_DacA1.1, J_DacOut1.1, RA_DAC1.2
unnamed: C_DacB1.1, J_DacOut1.3, RB_DAC1.2
unnamed: F1.2, SW1.2 (B)
unnamed: RA_DAC1.1, U1.8 (VA)
unnamed: RB_DAC1.1, U1.6 (VB)
unnamed: C6.1, R_usb2.1, Rusb1.2, U5.1 (ADJ)

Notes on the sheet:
CLK
SD-CS
SD-MISO
SD-MOSI
0V/Gnd
DIN
DOUT
TFT-LED
T-CS
TFT-RESET
TFT-DC
TFT-CS
T-CLK
T-DIN
connection to USB NANO ...
+5V
IRQ
TFT-SCK
SD-SCK
TFT-MOSI
T-DO
T-IRQ
+3.9V
TFT-MISO
In+

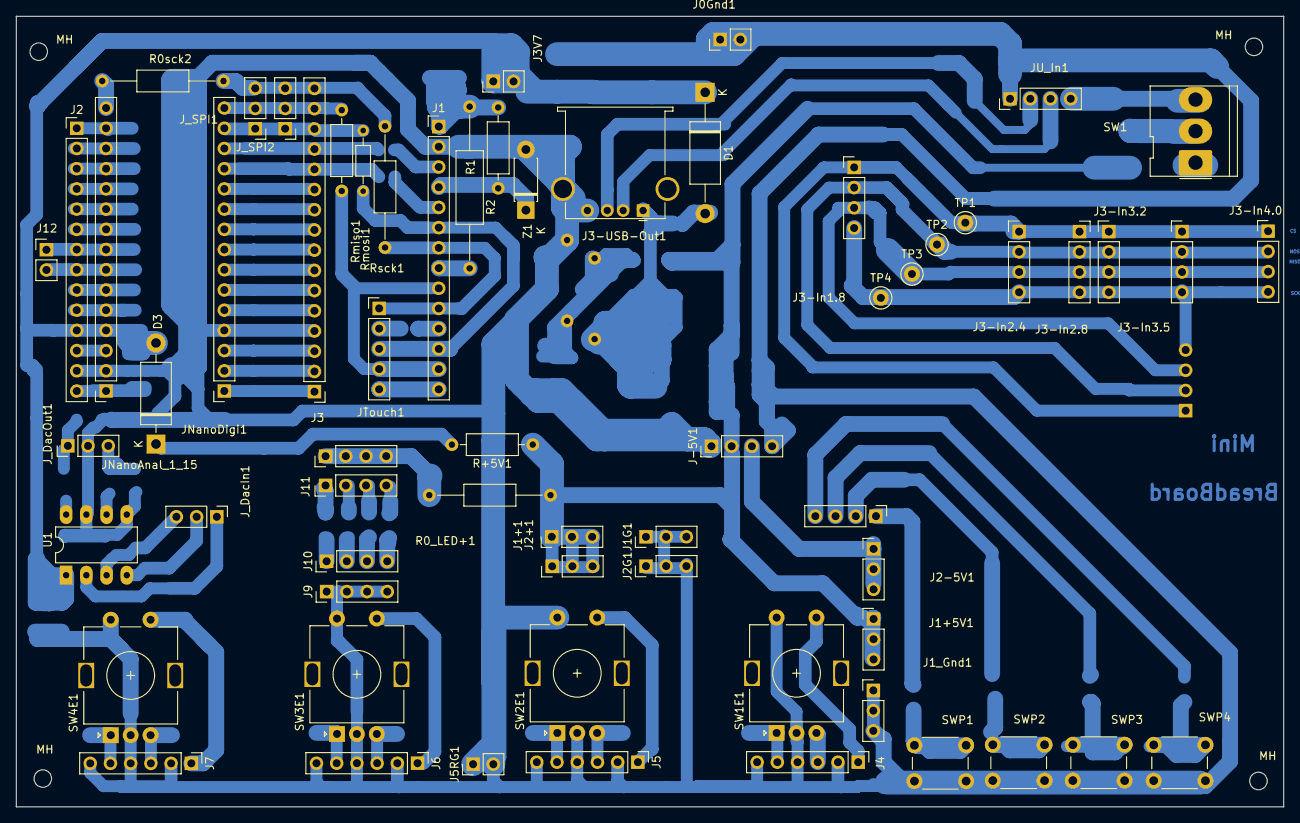
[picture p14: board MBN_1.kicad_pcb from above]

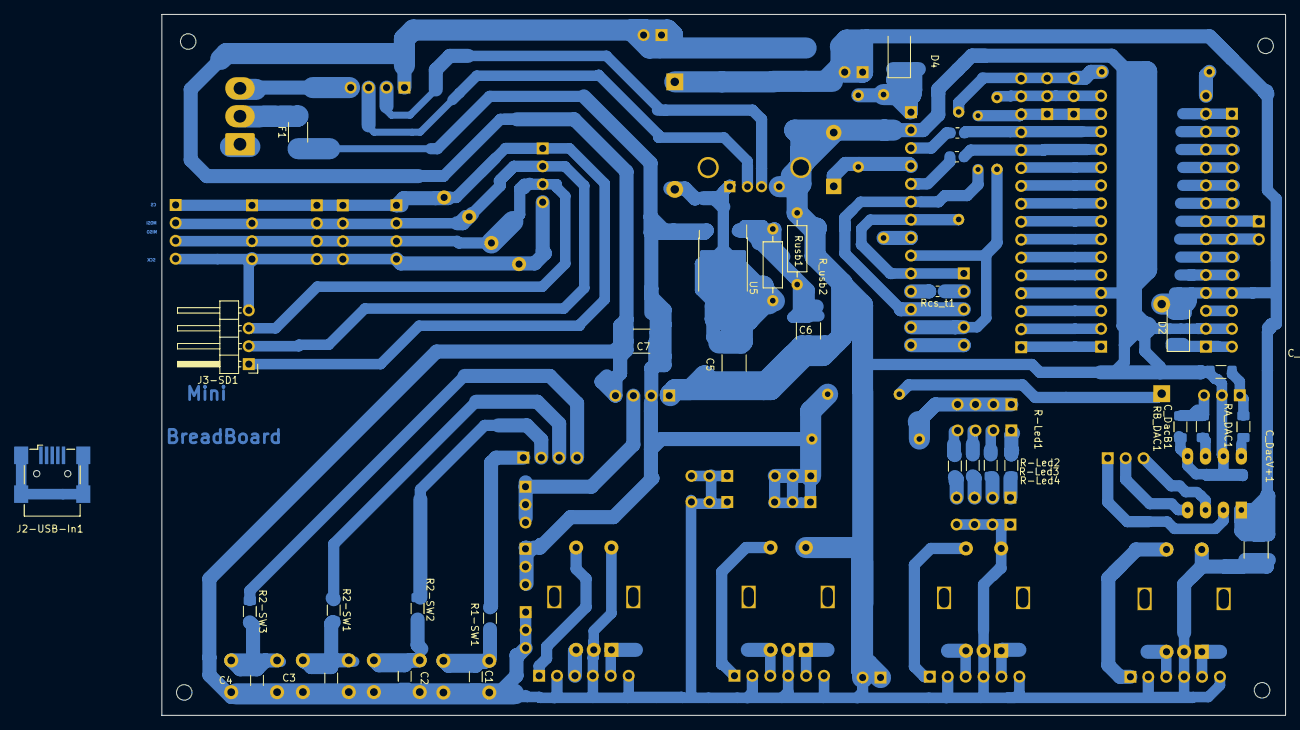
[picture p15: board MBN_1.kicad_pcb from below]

Board: 2 copper layers, 159.3 x 99.3 mm, 99 parts (31 on the bottom side), 90 nets.

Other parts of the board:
MH: MH_2.2; MountingHole_2.2mm_M2_DIN965
MH#2, MH#3, MH#4: MH_2.2; MountingHole_2.2mm_M2_DIN965

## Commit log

2023-12-09 Add files via upload
    .
    Test Board für Arduino „NANOs“ mit ILI9341, ILI9488-bzw. ST7735 SPI-Display
    Bei vielen meiner Projekte verwende ich den Arduino NANO oder Pin-kompatible Prozessoren mit dem TFT-Farb-Display ILI9341 bzw. ILI9488 bzw. ST7735 aus folgenden Gründen:
    • Existenz vieler Bibliotheken (libs) mit zahlreichen Beispielen für Prozessor und Display
    • kompaktes Board mit relativ grosser Anzahl herausgeführter Pins für andere Funktionen,
    • leicht beschaffbar / preisgünstig
    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
2023-12-09 Update README.md
    • Existenz von „NANO“ Boards mit anderem Processor mit NANO-“Pin-mapping“
    • mit HW-SPI ist das Display -auch am NANO – relativ schnell
    • die SP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
2023-12-09 Update README.doc
    • die S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
